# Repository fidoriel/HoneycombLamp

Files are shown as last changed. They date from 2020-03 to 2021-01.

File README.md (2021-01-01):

# HoneycombLamp

Parts List
1 Small Arduino e.g. Pro Mini, nano
White Filament (very important)
ca. 1M WS2812b LED Strip minimum 30LED/M better 60LED/M
1x Button
1x Resistor 1kO

Print Information
0.16 mm Layer hight
10% Infill
White PLA
0.4 mm Nozzle
good retraction settings needed
Pay attention that the inner shell has only one perimeter. Otherwise it will not be translucent.

Wiring information can be found in the .ino file and in the Wiring folder.

.stl files are licensed under the Creative Commons Attribution-NonCommercial 4.0 International License.

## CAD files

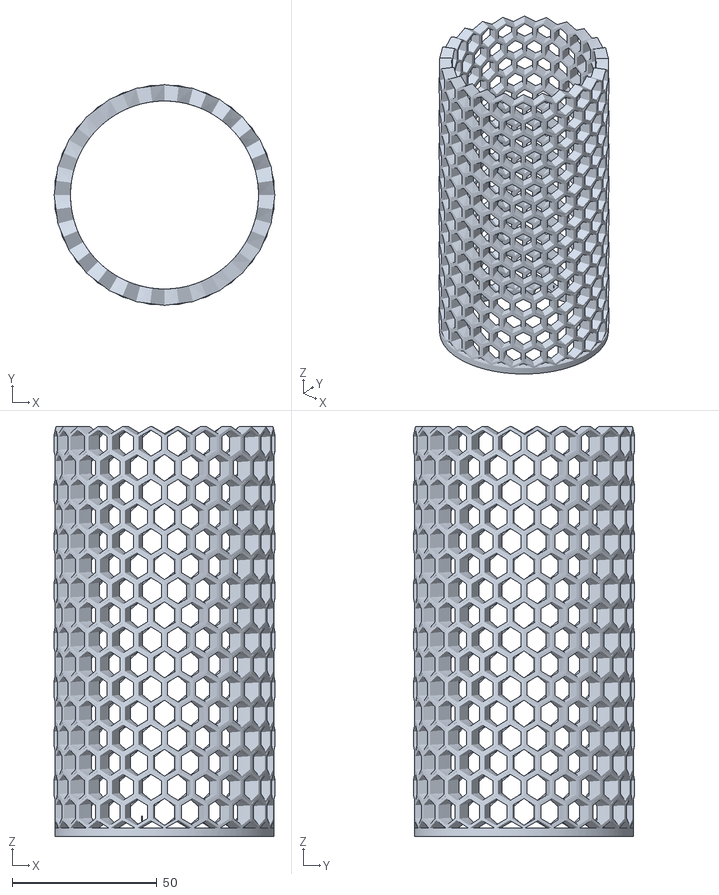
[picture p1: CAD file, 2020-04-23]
LampMultiMaterial/OnlyMultiMaterialOuter.stl
76.4 x 76.4 x 141.8

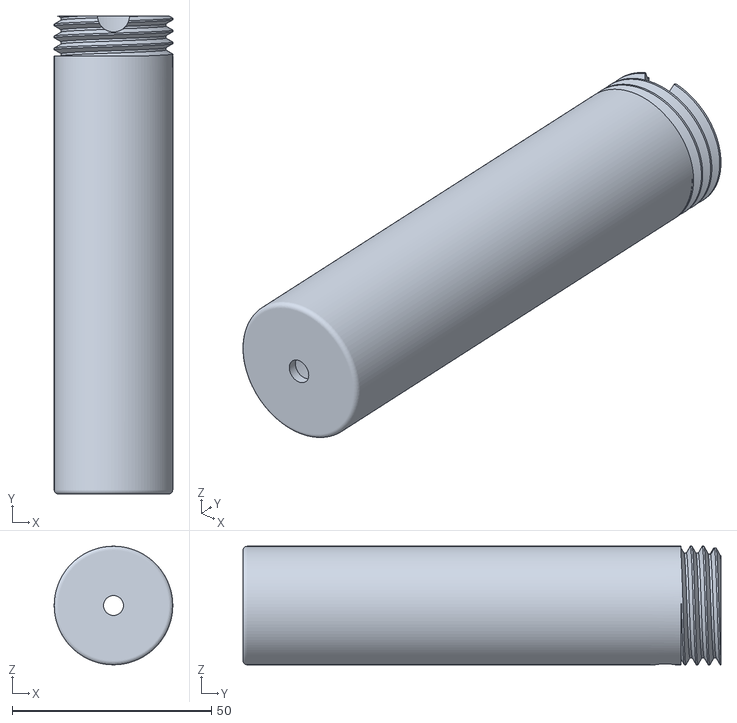
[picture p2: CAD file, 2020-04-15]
Leuchtmittel.stl
29.8 x 120.0 x 29.8

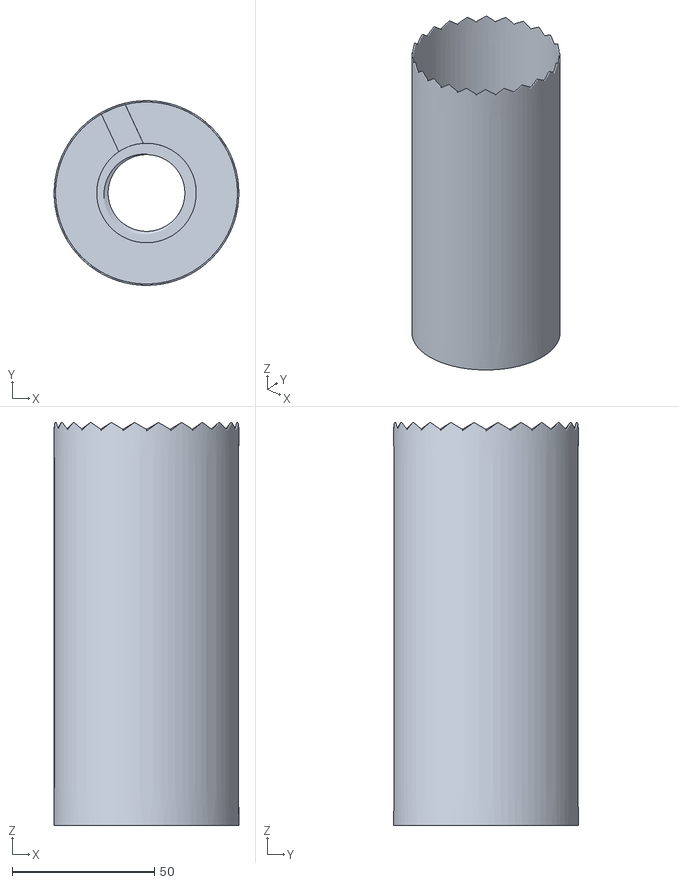
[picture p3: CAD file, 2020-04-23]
LampMultiMaterial/OnlyMultiMaterialInner.stl
65.0 x 65.0 x 141.8

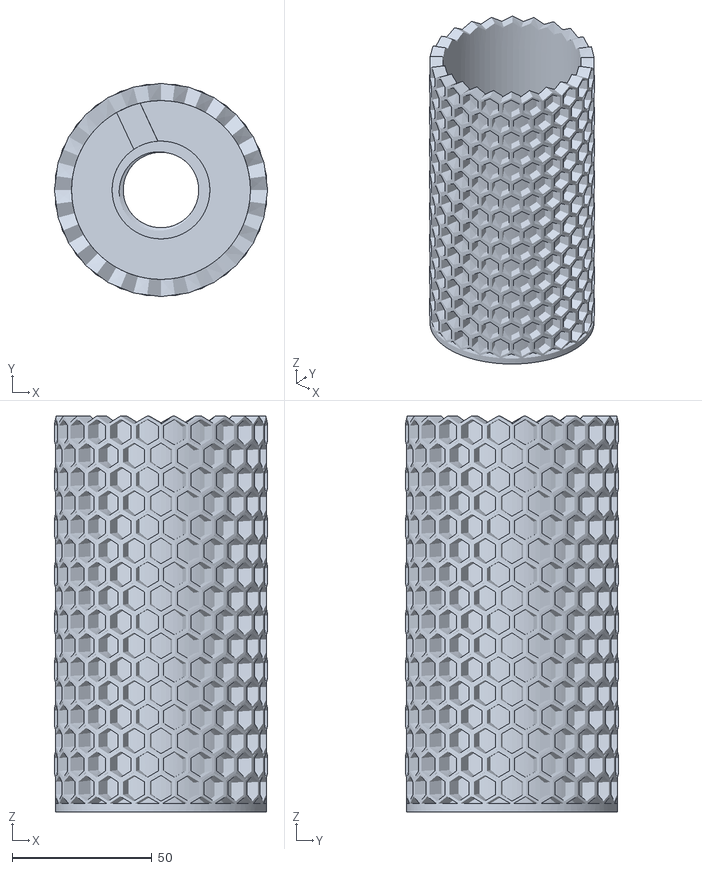
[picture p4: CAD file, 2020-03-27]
Schirm.stl
76.4 x 76.4 x 141.8

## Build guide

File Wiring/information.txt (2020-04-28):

Wiring:

Needed to connect to to 5V DC power source for example iPhone charger.
The button can be glued on to the top as seen in the picture. This button toggles the modes of the lamp.
The .ino file needs to be uploaded to an Arduino compatible board. Tutorials can be found on the internet. You need to adjust the PIXEL_COUNT variable in the .ino file to fit the number of LEDs on your strip. You also need to install the Adafruit_NeoPixel library. This can be done with the library manager in the Arduino IDE.
The soldered Arduino and wiring can be housed in the lamp. Solder skills required. Use shrinking tube to avoid short circuits.

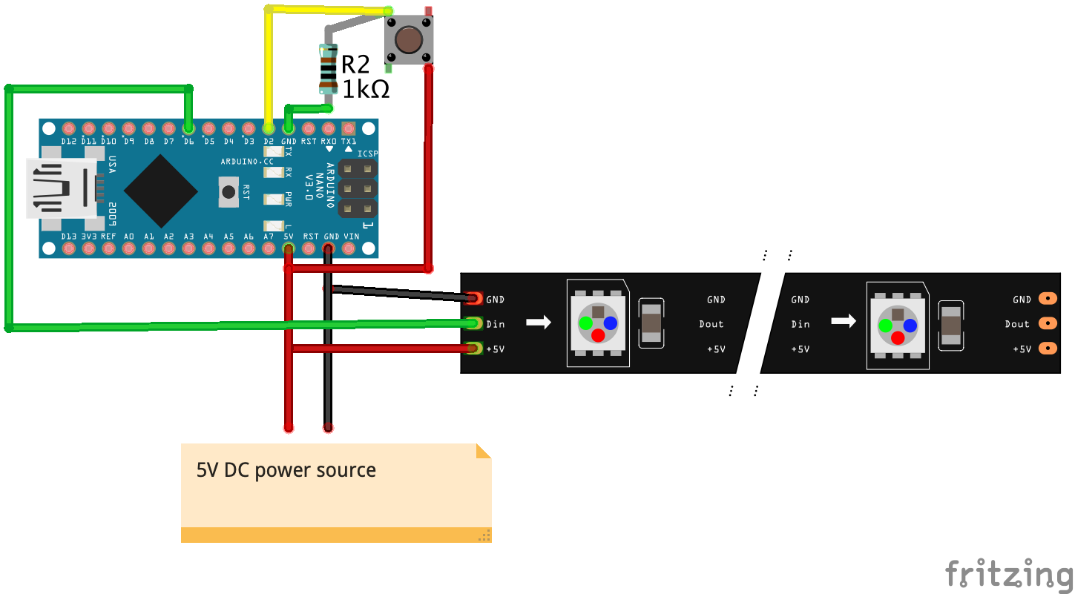
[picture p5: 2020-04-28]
Wiring/Wiring_Steckplatine.png

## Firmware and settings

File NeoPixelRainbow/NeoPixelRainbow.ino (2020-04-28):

/*
The MIT License (MIT)

Copyright © 2020 fidoriel
Permission is hereby granted, free of charge, to any person obtaining a copy of this software and associated documentation files (the “Software”),
to deal in the Software without restriction, including without limitation the rights to use, copy, modify, merge, publish, distribute, sublicense,
and/or sell copies of the Software, and to permit persons to whom the Software is furnished to do so, subject to the following conditions:
The above copyright notice and this permission notice shall be included in all copies or substantial portions of the Software.
THE SOFTWARE IS PROVIDED “AS IS”, WITHOUT WARRANTY OF ANY KIND, EXPRESS OR IMPLIED, INCLUDING BUT NOT LIMITED TO THE WARRANTIES OF MERCHANTABILITY,
FITNESS FOR A PARTICULAR PURPOSE AND NONINFRINGEMENT. IN NO EVENT SHALL THE AUTHORS OR COPYRIGHT HOLDERS BE LIABLE FOR ANY CLAIM, DAMAGES OR OTHER LIABILITY,
WHETHER IN AN ACTION OF CONTRACT, TORT OR OTHERWISE, ARISING FROM, OUT OF OR IN CONNECTION WITH THE SOFTWARE OR THE USE OR OTHER DEALINGS IN THE SOFTWARE.
 */

#include <Adafruit_NeoPixel.h>

// 5V -> Button, Button Out -> 2 and GND -> 2 Resistor 1kO
#define BUTTON_PIN   2
#define PIXEL_PIN    6  // Digital IO pin connected to the NeoPixels.
#define PIXEL_COUNT 28  // Number of NeoPixels
bool activateMode = 0;
int mode = 0;
int randomNr = 0;


Adafruit_NeoPixel strip(PIXEL_COUNT, PIXEL_PIN, NEO_GRB + NEO_KHZ800);

void setup() {
  pinMode(BUTTON_PIN, INPUT_PULLUP);
  strip.begin(); // Initialize NeoPixel strip object (REQUIRED)
  strip.show();  // Initialize all pixels to 'off'
}

void loop() {
      if (digitalRead(BUTTON_PIN)){
        delay(500); //debounce
        mode+=1;
        if (mode>=(11+1)){mode=0;}
      }

      else if (mode==0){
        rainbow(25);
      }

      else if (mode==1){
        for (int i = 0; i < PIXEL_COUNT; i++){
          strip.setPixelColor(i, 255, 255, 75); // warm white
        }
        strip.show();
      }

      else if (mode==2){
        for (int i = 0; i < PIXEL_COUNT; i++){
          strip.setPixelColor(i, 255, 0, 0); // red
        }
        strip.show();
      }

      else if (mode==3){
        for (int i = 0; i < PIXEL_COUNT; i++){
          strip.setPixelColor(i, 0, 255, 0); // green
        }
        strip.show();
      }

      else if (mode==4){
        for (int i = 0; i < PIXEL_COUNT; i++){
          strip.setPixelColor(i, 0, 0, 255); // blue
        }
        strip.show();
      }

      else if (mode==5){
        for (int i = 0; i < PIXEL_COUNT; i++){
          strip.setPixelColor(i, 0, 255, 255); // light blue
        }
        strip.show();
      }

      else if (mode==6){
        for (int i = 0; i < PIXEL_COUNT; i++){
          strip.setPixelColor(i, 255, 255, 255); // white
        }
        strip.show();
      }

      else if (mode==7){
        for (int i = 0; i < PIXEL_COUNT; i++){
          strip.setPixelColor(i, 250, 95, 237); // light purple
        }
        strip.show();
      }

      else if (mode==8){
        for (int i = 0; i < PIXEL_COUNT; i++){
          strip.setPixelColor(i, 255, 171, 74); // orange
        }
        strip.show();
      }

      else if (mode==9){
        slow(500);
      }

      else if (mode==10){
        randomColor(150);        
      }

      else if (mode==11){
        wipe(100);    
      }
    }


// Rainbow cycle along whole strip. Pass delay time (in ms) between frames.
void rainbow(int wait) {

  for(long firstPixelHue = 0; firstPixelHue < 3*65536; firstPixelHue += 256) {
    for(int i=0; i<strip.numPixels(); i++) { // For each pixel in strip...
      if (digitalRead(BUTTON_PIN)){
        mode+=1;
        delay(500);
        return;
      }
      // Offset pixel hue by an amount to make one full revolution of the
      // color wheel (range of 65536) along the length of the strip
      // (strip.numPixels() steps):
      int pixelHue = firstPixelHue + (i * 65536L / strip.numPixels());
      // strip.ColorHSV() can take 1 or 3 arguments: a hue (0 to 65535) or
      // optionally add saturation and value (brightness) (each 0 to 255).
      // Here we're using just the single-argument hue variant. The result
      // is passed through strip.gamma32() to provide 'truer' colors
      // before assigning to each pixel:
      strip.setPixelColor(i, strip.gamma32(strip.ColorHSV(pixelHue)));
    }
    strip.show(); // Update strip with new contents
    delay(wait);  // Pause for a moment
  }
}

void slow(int wait){
  for (unsigned long int i = 0; i < strip.numPixels(); i++){
    if (digitalRead(BUTTON_PIN)){
        mode+=1;
        return;
    }
    randomNr = random(0,255);
    strip.setPixelColor(i, 0, randomNr, randomNr);
  }
  strip.show();
  for (int i = 0; i < wait; i++){
    if (digitalRead(BUTTON_PIN)){
        mode+=1;
        delay(500);
        return;
    }
    delay(1);
  }
}

void randomColor(int wait){
    for (unsigned long int i = 0; i < strip.numPixels(); i++){
      for (int i = 0; i < wait; i++){
        if (digitalRead(BUTTON_PIN)){
          mode+=1;
          delay(500);
          return;
        }
      }
      strip.setPixelColor(i, random(0,255), random(0,255), random(0,255));
      }
    strip.show();
    for (int i = 0; i < wait; i++){
      if (digitalRead(BUTTON_PIN)){
        mode+=1;
        delay(500);
        return;
      }
      delay(1);
    }
}


void wipe(int colorWipeTime){
  if (colorWipe(strip.Color(255,   0,   0), colorWipeTime)){
    return;
  }
  if (colorWipe(strip.Color(255,   255,   0), colorWipeTime)){
    return;
  }
  if (colorWipe(strip.Color(0,   255,   0), colorWipeTime)){
    return;
  }
  if (colorWipe(strip.Color(0,   255,   255), colorWipeTime)){
    return;
  }
  if (colorWipe(strip.Color(0,   0,   255), colorWipeTime)){
    return;
  }
  if (colorWipe(strip.Color(255,   0,   255), colorWipeTime)){
    return;
  }
}

bool colorWipe(uint32_t color, int wait) {
  for(int i=0; i<strip.numPixels(); i++) { // For each pixel in strip...
    strip.setPixelColor(i, color);         //  Set pixel's color (in RAM)
    strip.show();                          //  Update strip to match
    for (int i = 0; i < wait; i++){
      if (digitalRead(BUTTON_PIN)){
        mode+=1;
        delay(200);
        return true;
      }
      delay(1);
    }
  }
  return false;
}

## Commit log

2020-04-21 Add multi material
    [OnlyMultiMaterialInner.stl, OnlyMultiMaterialOuter.stl]
2020-04-23 changed MM version
    [OnlyMultiMaterialExampleSettings.3mf, OnlyMultiMaterialInner.stl, OnlyMultiMaterialOuter.stl]
2020-04-28 added wiring and license information
    [Wiring.fzz]
